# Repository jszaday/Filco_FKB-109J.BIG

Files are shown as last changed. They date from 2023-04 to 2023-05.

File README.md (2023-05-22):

# Universa Universis
Retrofit PCB for various Alps full-sized keyboards.

## Planned support:
- AEK (ANSI, EUR, JPN)
- DELL AT101W (ANSI, EUR, JPN)
- DELL AT101 (ANSI, EUR, JPN)
- Strong Man SMK-8851 (BAE, JPN)

## Version History:

### Alpha Revision

Front:
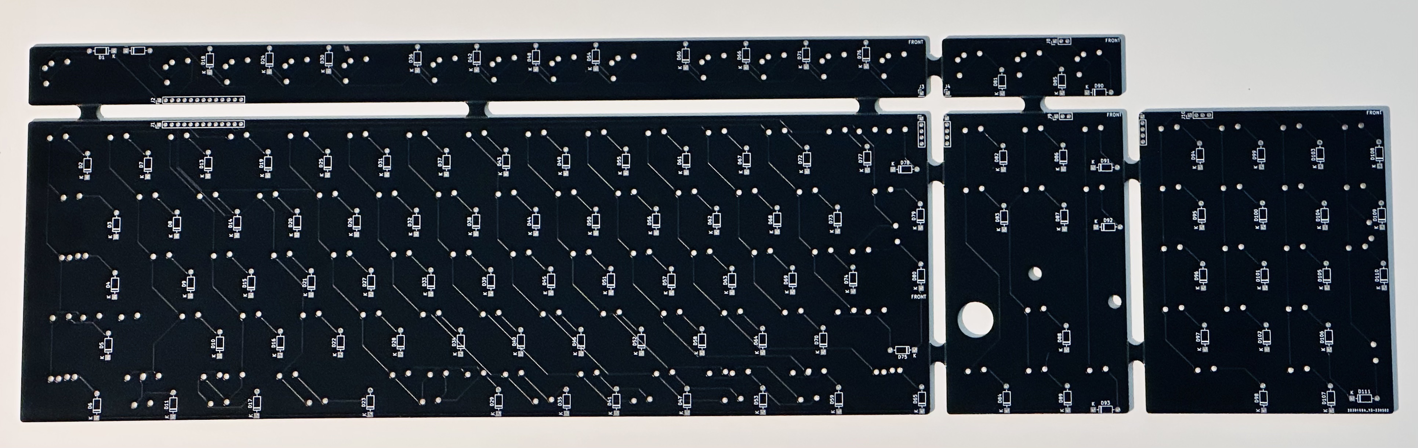
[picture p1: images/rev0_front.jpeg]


Back:
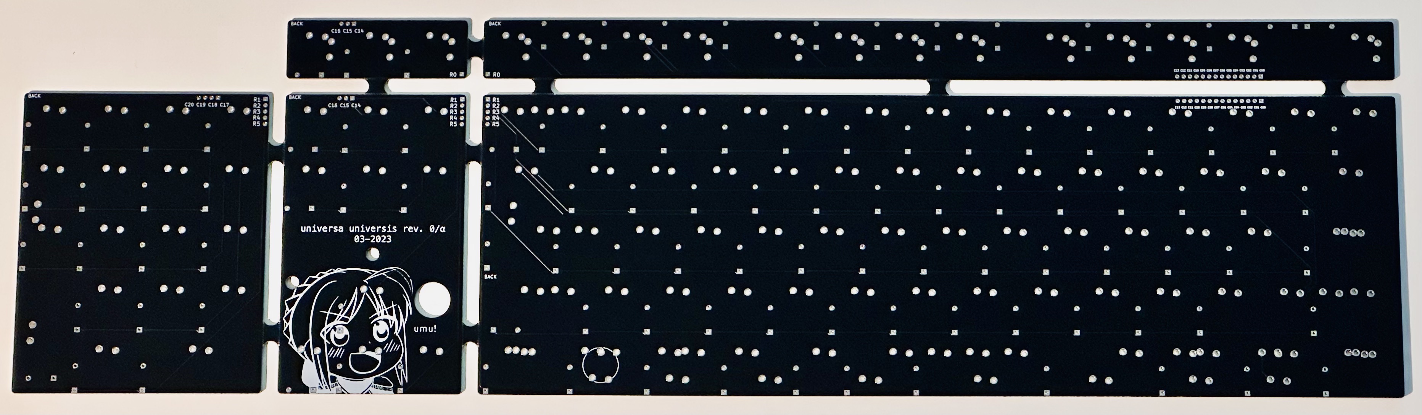
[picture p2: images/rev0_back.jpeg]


#### Known Issues
- DELL AT101 support impeded by unpopable popout between RAlt and RCtrl.
- ISO Enter in wrong position (1.5u vs. 1u); can fold down leads of switch to compensate.
- Num pad plus and enter key switches rotated 180° (not a significant issue).
- No LED carrier board.

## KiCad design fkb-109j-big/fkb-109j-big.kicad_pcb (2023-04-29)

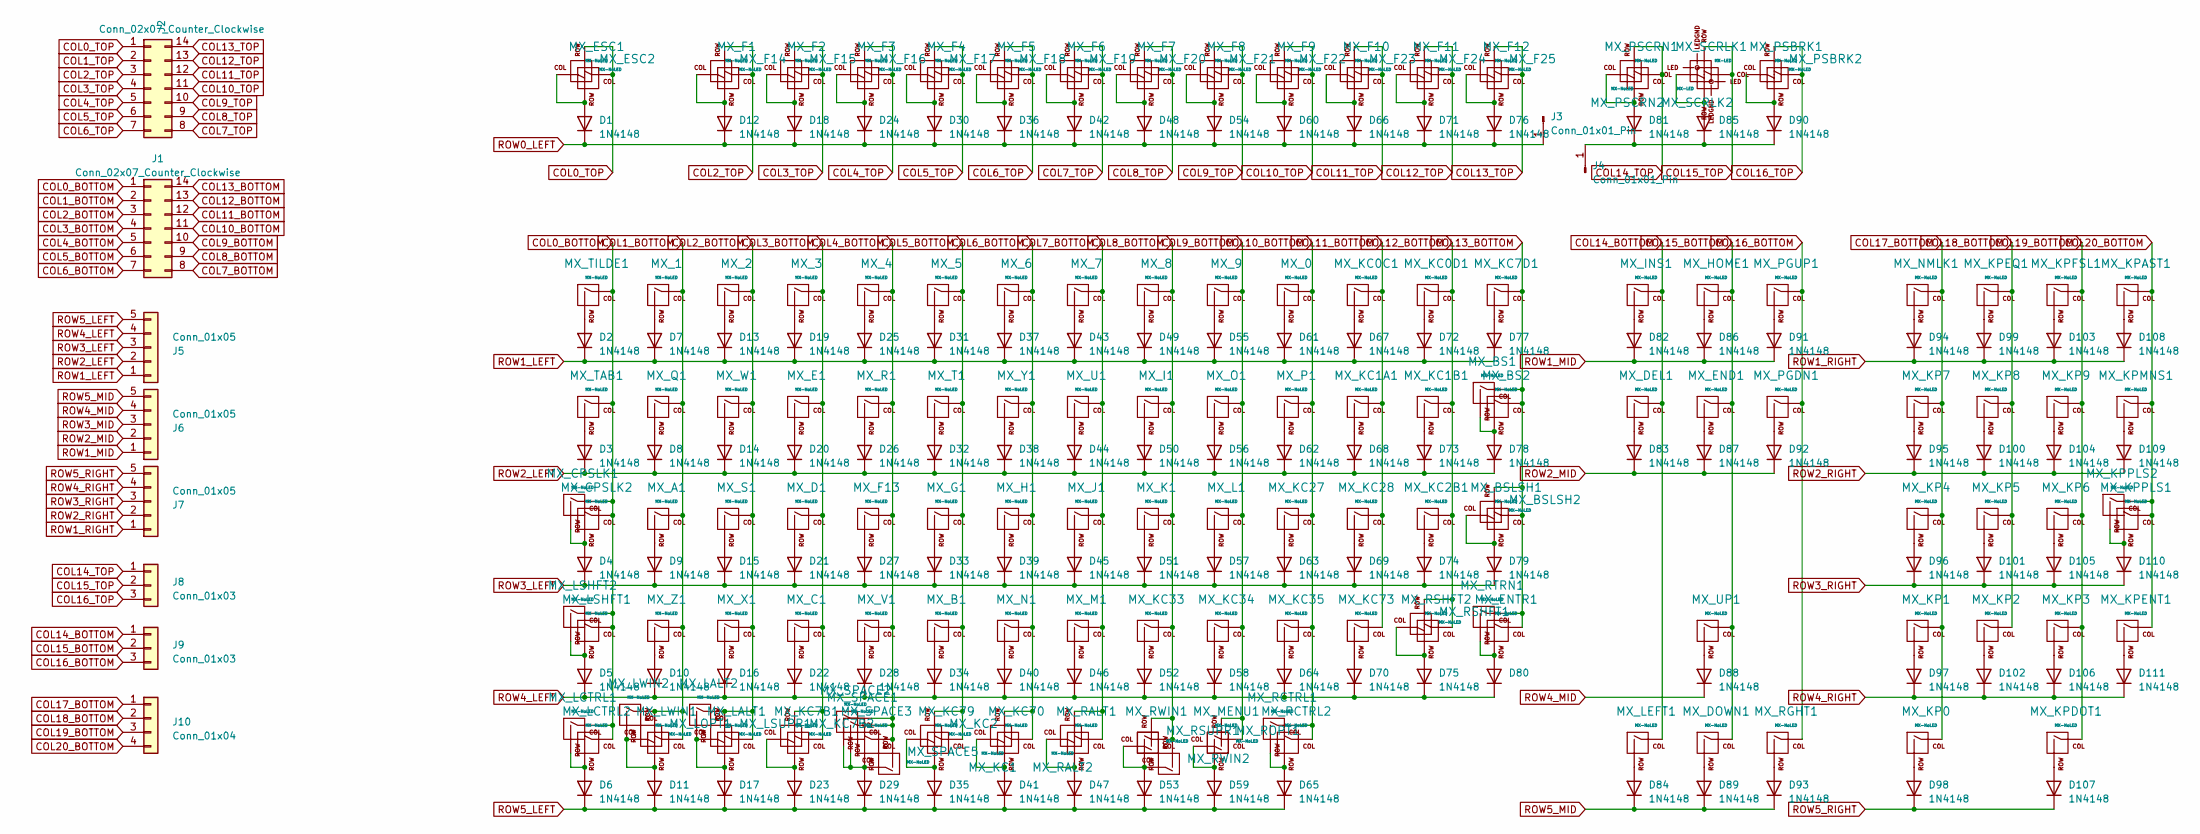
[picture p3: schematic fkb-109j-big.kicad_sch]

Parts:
D1, D2, D3, D4, D5, D6, D7, D8, D9, D10, D11, D12, D13, D14, D15, D16, D17, D18, D19, D20, D21, D22, D23, D24, D25, D26, D27, D28, D29, D30, D31, D32, D33, D34, D35, D36, D37, D38, D39, D40, D41, D42, D43, D44, D45, D46, D47, D48, D49, D50, D51, D52, D53, D54, D55, D56, D57, D58, D59, D60, D61, D62, D63, D64, D65, D66, D67, D68, D69, D70, D71, D72, D73, D74, D75, D76, D77, D78, D79, D80, D81, D82, D83, D84, D85, D86, D87, D88, D89, D90, D91, D92, D93, D94, D95, D96, D97, D98, D99, D100, D101, D102, D103, D104, D105, D106, D107, D108, D109, D110, D111: 1N4148; D_DO-35_SOD27_P7.62mm_Horizontal
J1, J2: Conn_02x07_Counter_Clockwise; PinHeader_1x14_P2.00mm_Vertical
J3, J4: Conn_01x01_Pin; PinHeader_1x01_P2.00mm_Vertical
J5, J6, J7: Conn_01x05; PinHeader_1x05_P2.00mm_Vertical
J8, J9: Conn_01x03; PinHeader_1x03_P2.00mm_Vertical
J10: Conn_01x04; PinHeader_1x04_P2.00mm_Vertical
MX_0, MX_1, MX_2, MX_3, MX_4, MX_5, MX_6, MX_7, MX_8, MX_9: MX-NoLED; ALPS-1U
MX_A1: MX-NoLED; ALPS-1U
MX_B1: MX-NoLED; ALPS-1U
MX_BS1: MX-NoLED; ALPS-1U
MX_BS2: MX-NoLED; ALPS-2U
MX_BSLSH1: MX-NoLED; ALPS-1.5U
MX_BSLSH2: MX-NoLED; ALPS-1U
MX_C1: MX-NoLED; ALPS-1U
MX_CPSLK1: MX-NoLED; ALPS-1.5U
MX_CPSLK2: MX-NoLED; ALPS-1.75U
MX_D1: MX-NoLED; ALPS-1U
MX_DEL1: MX-NoLED; ALPS-1U
MX_DOWN1: MX-NoLED; ALPS-1U
MX_E1: MX-NoLED; ALPS-1U
MX_END1: MX-NoLED; ALPS-1U
MX_ENTR1: MX-NoLED; ALPS-2U
MX_ESC1, MX_ESC2: MX-NoLED; ALPS-1U
MX_F1, MX_F2, MX_F3, MX_F4, MX_F5, MX_F6, MX_F7, MX_F8, MX_F9, MX_F10, MX_F11, MX_F12, MX_F13, MX_F14, MX_F15, MX_F16, MX_F17, MX_F18, MX_F19, MX_F20, MX_F21, MX_F22, MX_F23, MX_F24, MX_F25: MX-NoLED; ALPS-1U
MX_G1: MX-NoLED; ALPS-1U
MX_H1: MX-NoLED; ALPS-1U
MX_HOME1: MX-NoLED; ALPS-1U
MX_I1: MX-NoLED; ALPS-1U
MX_INS1: MX-NoLED; ALPS-1U
MX_J1: MX-NoLED; ALPS-1U
MX_K1: MX-NoLED; ALPS-1U
MX_KC0C1, MX_KC0D1, MX_KC1A1, MX_KC1B1, MX_KC2B1, MX_KC7D1, MX_KC27, MX_KC28, MX_KC33, MX_KC34, MX_KC35, MX_KC73: MX-NoLED; ALPS-1U
MX_KC1: MX-NoLED; ALPS-1.5U
MX_KC2, MX_KC7B2: MX-NoLED; ALPS-1.75U
MX_KC7B1, MX_KC70, MX_KC79: MX-NoLED; ALPS-1.25U
MX_KP0: MX-NoLED; ALPS-2U
MX_KP1, MX_KP2, MX_KP3, MX_KP4, MX_KP5, MX_KP6, MX_KP7, MX_KP8, MX_KP9: MX-NoLED; ALPS-1U
MX_KPAST1: MX-NoLED; ALPS-1U
MX_KPDOT1: MX-NoLED; ALPS-1U
MX_KPENT1: MX-NoLED; ALPS-2U
MX_KPEQ1: MX-NoLED; ALPS-1U
MX_KPFSL1: MX-NoLED; ALPS-1U
MX_KPMNS1: MX-NoLED; ALPS-1U
MX_KPPLS1: MX-NoLED; ALPS-1U
MX_KPPLS2: MX-NoLED; ALPS-2U
MX_L1: MX-NoLED; ALPS-1U
MX_LALT1: MX-NoLED; ALPS-1.25U
MX_LALT2: MX-NoLED; ALPS-1.5U
MX_LCTRL1: MX-NoLED; ALPS-1.25U
MX_LCTRL2: MX-NoLED; ALPS-1.5U
MX_LEFT1: MX-NoLED; ALPS-1U
MX_LOPT1: MX-NoLED; ALPS-1.25U
MX_LSHFT1: MX-NoLED; ALPS-2.25U
MX_LSHFT2: MX-NoLED; ALPS-1.25U
MX_LSUPR1: MX-NoLED; ALPS-1.5U
MX_LWIN1: MX-NoLED; ALPS-1.25U
MX_LWIN2: MX-NoLED; ALPS-1U
MX_M1: MX-NoLED; ALPS-1U
MX_MENU1: MX-NoLED; ALPS-1.25U
MX_N1: MX-NoLED; ALPS-1U
MX_NMLK1: MX-NoLED; ALPS-1U
MX_O1: MX-NoLED; ALPS-1U
MX_P1: MX-NoLED; ALPS-1U
MX_PGDN1: MX-NoLED; ALPS-1U
MX_PGUP1: MX-NoLED; ALPS-1U
MX_PSBRK1, MX_PSBRK2: MX-NoLED; ALPS-1U
MX_PSCRN1, MX_PSCRN2: MX-NoLED; ALPS-1U
MX_Q1: MX-NoLED; ALPS-1U
MX_R1: MX-NoLED; ALPS-1U
MX_RALT1: MX-NoLED; ALPS-1.25U
MX_RALT2: MX-NoLED; ALPS-1.5U
MX_RCTRL1: MX-NoLED; ALPS-1.25U
MX_RCTRL2: MX-NoLED; ALPS-1.5U
MX_RGHT1: MX-NoLED; ALPS-1U
MX_ROPT1: MX-NoLED; ALPS-1.25U
MX_RSHFT1: MX-NoLED; ALPS-2.75U
MX_RSHFT2: MX-NoLED; ALPS-1.75U
MX_RSUPR1: MX-NoLED; ALPS-1.5U
MX_RTRN1: MX-NoLED; ALPS-2.25U
MX_RWIN1: MX-NoLED; ALPS-1.25U
MX_RWIN2: MX-NoLED; ALPS-1U
MX_S1: MX-NoLED; ALPS-1U
MX_SCRLK1, MX_SCRLK2: MX-LED; ALPS-1U
MX_SPACE1: MX-NoLED; ALPS-6.5U
MX_SPACE2: MX-NoLED; ALPS-6.25U
MX_SPACE3: MX-NoLED; ALPS-2.5U
MX_SPACE5: MX-NoLED; ALPS-2U
MX_T1: MX-NoLED; ALPS-1U
MX_TAB1: MX-NoLED; ALPS-1.5U
MX_TILDE1: MX-NoLED; ALPS-1U
MX_U1: MX-NoLED; ALPS-1U
MX_UP1: MX-NoLED; ALPS-1U
MX_V1: MX-NoLED; ALPS-1U
MX_W1: MX-NoLED; ALPS-1U
MX_X1: MX-NoLED; ALPS-1U
MX_Y1: MX-NoLED; ALPS-1U
MX_Z1: MX-NoLED; ALPS-1U

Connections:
COL0_BOTTOM: J1.1, MX_CPSLK1.1 (COL), MX_CPSLK2.1 (COL), MX_LCTRL1.1 (COL), MX_LCTRL2.1 (COL), MX_LSHFT1.1 (COL), MX_LSHFT2.1 (COL), MX_TAB1.1 (COL), MX_TILDE1.1 (COL)
COL0_TOP: J2.1, MX_ESC1.1 (COL), MX_ESC2.2 (ROW)
COL1_BOTTOM: J1.2, MX_1.1 (COL), MX_A1.1 (COL), MX_LOPT1.2 (ROW), MX_LWIN1.1 (COL), MX_LWIN2.1 (COL), MX_Q1.1 (COL), MX_Z1.1 (COL)
COL1_TOP: J2.2
COL2_BOTTOM: J1.3, MX_2.1 (COL), MX_LALT1.1 (COL), MX_LALT2.1 (COL), MX_LSUPR1.2 (ROW), MX_S1.1 (COL), MX_W1.1 (COL), MX_X1.1 (COL)
COL2_TOP: J2.3, MX_F1.1 (COL), MX_F14.2 (ROW)
COL3_BOTTOM: J1.4, MX_3.1 (COL), MX_C1.1 (COL), MX_D1.1 (COL), MX_E1.1 (COL), MX_KC7B1.1 (COL), MX_KC7B2.2 (ROW)
COL3_TOP: J2.4, MX_F2.1 (COL), MX_F15.2 (ROW)
COL4_BOTTOM: J1.5, MX_4.1 (COL), MX_F13.1 (COL), MX_R1.1 (COL), MX_SPACE1.1 (COL), MX_SPACE2.1 (COL), MX_SPACE3.1 (COL), MX_SPACE5.2 (ROW), MX_V1.1 (COL)
COL4_TOP: J2.5, MX_F3.1 (COL), MX_F16.2 (ROW)
COL5_BOTTOM: J1.6, MX_5.1 (COL), MX_B1.1 (COL), MX_G1.1 (COL), MX_KC2.2 (ROW), MX_KC79.1 (COL), MX_T1.1 (COL)
COL5_TOP: J2.6, MX_F4.1 (COL), MX_F17.2 (ROW)
COL6_BOTTOM: J1.7, MX_6.1 (COL), MX_H1.1 (COL), MX_KC1.2 (ROW), MX_KC70.1 (COL), MX_N1.1 (COL), MX_Y1.1 (COL)
COL6_TOP: J2.7, MX_F5.1 (COL), MX_F18.2 (ROW)
COL7_BOTTOM: J1.8, MX_7.1 (COL), MX_J1.1 (COL), MX_M1.1 (COL), MX_RALT1.1 (COL), MX_RALT2.2 (ROW), MX_U1.1 (COL)
COL7_TOP: J2.8, MX_F6.1 (COL), MX_F19.2 (ROW)
COL8_BOTTOM: J1.9, MX_8.1 (COL), MX_I1.1 (COL), MX_K1.1 (COL), MX_KC33.1 (COL), MX_RSUPR1.2 (ROW), MX_RWIN1.1 (COL), MX_RWIN2.2 (ROW)
COL8_TOP: J2.9, MX_F7.1 (COL), MX_F20.2 (ROW)
COL9_BOTTOM: J1.10, MX_9.1 (COL), MX_KC34.1 (COL), MX_L1.1 (COL), MX_MENU1.1 (COL), MX_O1.1 (COL), MX_ROPT1.2 (ROW)
COL9_TOP: J2.10, MX_F8.1 (COL), MX_F21.2 (ROW)
COL10_BOTTOM: J1.11, MX_0.1 (COL), MX_KC27.1 (COL), MX_KC35.1 (COL), MX_P1.1 (COL), MX_RCTRL1.1 (COL), MX_RCTRL2.1 (COL)
COL10_TOP: J2.11, MX_F9.1 (COL), MX_F22.2 (ROW)
COL11_BOTTOM: J1.12, MX_KC0C1.1 (COL), MX_KC1A1.1 (COL), MX_KC28.1 (COL), MX_KC73.1 (COL)
COL11_TOP: J2.12, MX_F10.1 (COL), MX_F23.2 (ROW)
COL12_BOTTOM: J1.13, MX_KC0D1.1 (COL), MX_KC1B1.1 (COL), MX_KC2B1.1 (COL), MX_RSHFT1.2 (ROW), MX_RSHFT2.1 (COL)
COL12_TOP: J2.13, MX_F11.1 (COL), MX_F24.2 (ROW)
COL13_BOTTOM: J1.14, MX_BS1.1 (COL), MX_BS2.1 (COL), MX_BSLSH1.1 (COL), MX_BSLSH2.2 (ROW), MX_ENTR1.1 (COL), MX_KC7D1.1 (COL), MX_RTRN1.1 (COL)
COL13_TOP: J2.14, MX_F12.1 (COL), MX_F25.2 (ROW)
COL14_BOTTOM: J9.1, MX_DEL1.1 (COL), MX_INS1.1 (COL), MX_LEFT1.1 (COL)
COL14_TOP: J8.1, MX_PSCRN1.1 (COL), MX_PSCRN2.2 (ROW)
COL15_BOTTOM: J9.2, MX_DOWN1.1 (COL), MX_END1.1 (COL), MX_HOME1.1 (COL), MX_UP1.1 (COL)
COL15_TOP: J8.2, MX_SCRLK1.1 (COL), MX_SCRLK2.2 (ROW)
COL16_BOTTOM: J9.3, MX_PGDN1.1 (COL), MX_PGUP1.1 (COL), MX_RGHT1.1 (COL)
COL16_TOP: J8.3, MX_PSBRK1.1 (COL), MX_PSBRK2.2 (ROW)
COL17_BOTTOM: J10.1, MX_KP0.1 (COL), MX_KP1.1 (COL), MX_KP4.1 (COL), MX_KP7.1 (COL), MX_NMLK1.1 (COL)
COL18_BOTTOM: J10.2, MX_KP2.1 (COL), MX_KP5.1 (COL), MX_KP8.1 (COL), MX_KPEQ1.1 (COL)
COL19_BOTTOM: J10.3, MX_KP3.1 (COL), MX_KP6.1 (COL), MX_KP9.1 (COL), MX_KPDOT1.1 (COL), MX_KPFSL1.1 (COL)
COL20_BOTTOM: J10.4, MX_KPAST1.1 (COL), MX_KPENT1.1 (COL), MX_KPMNS1.1 (COL), MX_KPPLS1.1 (COL), MX_KPPLS2.1 (COL)
unnamed: D1.2 (A), MX_ESC1.2 (ROW), MX_ESC2.1 (COL)
unnamed: D2.2 (A), MX_TILDE1.2 (ROW)
unnamed: D3.2 (A), MX_TAB1.2 (ROW)
unnamed: D4.2 (A), MX_CPSLK1.2 (ROW), MX_CPSLK2.2 (ROW)
unnamed: D5.2 (A), MX_LSHFT1.2 (ROW), MX_LSHFT2.2 (ROW)
unnamed: D6.2 (A), MX_LCTRL1.2 (ROW), MX_LCTRL2.2 (ROW)
unnamed: D7.2 (A), MX_1.2 (ROW)
unnamed: D8.2 (A), MX_Q1.2 (ROW)
unnamed: D9.2 (A), MX_A1.2 (ROW)
unnamed: D10.2 (A), MX_Z1.2 (ROW)
unnamed: D11.2 (A), MX_LOPT1.1 (COL), MX_LWIN1.2 (ROW), MX_LWIN2.2 (ROW)
unnamed: D12.2 (A), MX_F1.2 (ROW), MX_F14.1 (COL)
unnamed: D13.2 (A), MX_2.2 (ROW)
unnamed: D14.2 (A), MX_W1.2 (ROW)
unnamed: D15.2 (A), MX_S1.2 (ROW)
unnamed: D16.2 (A), MX_X1.2 (ROW)
unnamed: D17.2 (A), MX_LALT1.2 (ROW), MX_LALT2.2 (ROW), MX_LSUPR1.1 (COL)
unnamed: D18.2 (A), MX_F2.2 (ROW), MX_F15.1 (COL)
unnamed: D19.2 (A), MX_3.2 (ROW)
unnamed: D20.2 (A), MX_E1.2 (ROW)
unnamed: D21.2 (A), MX_D1.2 (ROW)
unnamed: D22.2 (A), MX_C1.2 (ROW)
unnamed: D23.2 (A), MX_KC7B1.2 (ROW), MX_KC7B2.1 (COL)
unnamed: D24.2 (A), MX_F3.2 (ROW), MX_F16.1 (COL)
unnamed: D25.2 (A), MX_4.2 (ROW)
unnamed: D26.2 (A), MX_R1.2 (ROW)
unnamed: D27.2 (A), MX_F13.2 (ROW)
unnamed: D28.2 (A), MX_V1.2 (ROW)
unnamed: D29.2 (A), MX_SPACE1.2 (ROW), MX_SPACE2.2 (ROW), MX_SPACE3.2 (ROW), MX_SPACE5.1 (COL)
unnamed: D30.2 (A), MX_F4.2 (ROW), MX_F17.1 (COL)
unnamed: D31.2 (A), MX_5.2 (ROW)
unnamed: D32.2 (A), MX_T1.2 (ROW)
unnamed: D33.2 (A), MX_G1.2 (ROW)
unnamed: D34.2 (A), MX_B1.2 (ROW)
unnamed: D35.2 (A), MX_KC2.1 (COL), MX_KC79.2 (ROW)
unnamed: D36.2 (A), MX_F5.2 (ROW), MX_F18.1 (COL)
unnamed: D37.2 (A), MX_6.2 (ROW)
unnamed: D38.2 (A), MX_Y1.2 (ROW)
unnamed: D39.2 (A), MX_H1.2 (ROW)
unnamed: D40.2 (A), MX_N1.2 (ROW)
unnamed: D41.2 (A), MX_KC1.1 (COL), MX_KC70.2 (ROW)
unnamed: D42.2 (A), MX_F6.2 (ROW), MX_F19.1 (COL)
unnamed: D43.2 (A), MX_7.2 (ROW)
unnamed: D44.2 (A), MX_U1.2 (ROW)
unnamed: D45.2 (A), MX_J1.2 (ROW)
unnamed: D46.2 (A), MX_M1.2 (ROW)
unnamed: D47.2 (A), MX_RALT1.2 (ROW), MX_RALT2.1 (COL)
unnamed: D48.2 (A), MX_F7.2 (ROW), MX_F20.1 (COL)
unnamed: D49.2 (A), MX_8.2 (ROW)
unnamed: D50.2 (A), MX_I1.2 (ROW)
unnamed: D51.2 (A), MX_K1.2 (ROW)
unnamed: D52.2 (A), MX_KC33.2 (ROW)
unnamed: D53.2 (A), MX_RSUPR1.1 (COL), MX_RWIN1.2 (ROW), MX_RWIN2.1 (COL)
unnamed: D54.2 (A), MX_F8.2 (ROW), MX_F21.1 (COL)
unnamed: D55.2 (A), MX_9.2 (ROW)
unnamed: D56.2 (A), MX_O1.2 (ROW)
unnamed: D57.2 (A), MX_L1.2 (ROW)
unnamed: D58.2 (A), MX_KC34.2 (ROW)
unnamed: D59.2 (A), MX_MENU1.2 (ROW), MX_ROPT1.1 (COL)
unnamed: D60.2 (A), MX_F9.2 (ROW), MX_F22.1 (COL)
unnamed: D61.2 (A), MX_0.2 (ROW)
unnamed: D62.2 (A), MX_P1.2 (ROW)
unnamed: D63.2 (A), MX_KC27.2 (ROW)
unnamed: D64.2 (A), MX_KC35.2 (ROW)
unnamed: D65.2 (A), MX_RCTRL1.2 (ROW), MX_RCTRL2.2 (ROW)
unnamed: D66.2 (A), MX_F10.2 (ROW), MX_F23.1 (COL)
unnamed: D67.2 (A), MX_KC0C1.2 (ROW)
unnamed: D68.2 (A), MX_KC1A1.2 (ROW)
unnamed: D69.2 (A), MX_KC28.2 (ROW)
unnamed: D70.2 (A), MX_KC73.2 (ROW)
unnamed: D71.2 (A), MX_F11.2 (ROW), MX_F24.1 (COL)
unnamed: D72.2 (A), MX_KC0D1.2 (ROW)
unnamed: D73.2 (A), MX_KC1B1.2 (ROW)
unnamed: D74.2 (A), MX_KC2B1.2 (ROW)
unnamed: D75.2 (A), MX_RSHFT1.1 (COL), MX_RSHFT2.2 (ROW)
unnamed: D76.2 (A), MX_F12.2 (ROW), MX_F25.1 (COL)
unnamed: D77.2 (A), MX_KC7D1.2 (ROW)
unnamed: D78.2 (A), MX_BS1.2 (ROW), MX_BS2.2 (ROW)
unnamed: D79.2 (A), MX_BSLSH1.2 (ROW), MX_BSLSH2.1 (COL)
unnamed: D80.2 (A), MX_ENTR1.2 (ROW), MX_RTRN1.2 (ROW)
unnamed: D81.2 (A), MX_PSCRN1.2 (ROW), MX_PSCRN2.1 (COL)
unnamed: D81.1 (K), D85.1 (K), D90.1 (K), J4.1
unnamed: D82.2 (A), MX_INS1.2 (ROW)
unnamed: D83.2 (A), MX_DEL1.2 (ROW)
unnamed: D84.2 (A), MX_LEFT1.2 (ROW)
unnamed: D85.2 (A), MX_SCRLK1.2 (ROW), MX_SCRLK2.1 (COL)
unnamed: D86.2 (A), MX_HOME1.2 (ROW)
unnamed: D87.2 (A), MX_END1.2 (ROW)
unnamed: D88.2 (A), MX_UP1.2 (ROW)
unnamed: D89.2 (A), MX_DOWN1.2 (ROW)
unnamed: D90.2 (A), MX_PSBRK1.2 (ROW), MX_PSBRK2.1 (COL)
unnamed: D91.2 (A), MX_PGUP1.2 (ROW)
unnamed: D92.2 (A), MX_PGDN1.2 (ROW)
unnamed: D93.2 (A), MX_RGHT1.2 (ROW)
unnamed: D94.2 (A), MX_NMLK1.2 (ROW)
unnamed: D95.2 (A), MX_KP7.2 (ROW)
unnamed: D96.2 (A), MX_KP4.2 (ROW)
unnamed: D97.2 (A), MX_KP1.2 (ROW)
unnamed: D98.2 (A), MX_KP0.2 (ROW)
unnamed: D99.2 (A), MX_KPEQ1.2 (ROW)
unnamed: D100.2 (A), MX_KP8.2 (ROW)
unnamed: D101.2 (A), MX_KP5.2 (ROW)
unnamed: D102.2 (A), MX_KP2.2 (ROW)
unnamed: D103.2 (A), MX_KPFSL1.2 (ROW)
unnamed: D104.2 (A), MX_KP9.2 (ROW)
unnamed: D105.2 (A), MX_KP6.2 (ROW)
unnamed: D106.2 (A), MX_KP3.2 (ROW)
unnamed: D107.2 (A), MX_KPDOT1.2 (ROW)
unnamed: D108.2 (A), MX_KPAST1.2 (ROW)
unnamed: D109.2 (A), MX_KPMNS1.2 (ROW)
unnamed: D110.2 (A), MX_KPPLS1.2 (ROW), MX_KPPLS2.2 (ROW)
unnamed: D111.2 (A), MX_KPENT1.2 (ROW)
ROW0_LEFT: D1.1 (K), D12.1 (K), D18.1 (K), D24.1 (K), D30.1 (K), D36.1 (K), D42.1 (K), D48.1 (K), D54.1 (K), D60.1 (K), D66.1 (K), D71.1 (K), D76.1 (K), J3.1
ROW1_LEFT: D2.1 (K), D7.1 (K), D13.1 (K), D19.1 (K), D25.1 (K), D31.1 (K), D37.1 (K), D43.1 (K), D49.1 (K), D55.1 (K), D61.1 (K), D67.1 (K), D72.1 (K), D77.1 (K), J5.1
ROW1_MID: D82.1 (K), D86.1 (K), D91.1 (K), J6.1
ROW1_RIGHT: D94.1 (K), D99.1 (K), D103.1 (K), D108.1 (K), J7.1
ROW2_LEFT: D3.1 (K), D8.1 (K), D14.1 (K), D20.1 (K), D26.1 (K), D32.1 (K), D38.1 (K), D44.1 (K), D50.1 (K), D56.1 (K), D62.1 (K), D68.1 (K), D73.1 (K), D78.1 (K), J5.2
ROW2_MID: D83.1 (K), D87.1 (K), D92.1 (K), J6.2
ROW2_RIGHT: D95.1 (K), D100.1 (K), D104.1 (K), D109.1 (K), J7.2
ROW3_LEFT: D4.1 (K), D9.1 (K), D15.1 (K), D21.1 (K), D27.1 (K), D33.1 (K), D39.1 (K), D45.1 (K), D51.1 (K), D57.1 (K), D63.1 (K), D69.1 (K), D74.1 (K), D79.1 (K), J5.3
ROW3_MID: J6.3
ROW3_RIGHT: D96.1 (K), D101.1 (K), D105.1 (K), D110.1 (K), J7.3
ROW4_LEFT: D5.1 (K), D10.1 (K), D16.1 (K), D22.1 (K), D28.1 (K), D34.1 (K), D40.1 (K), D46.1 (K), D52.1 (K), D58.1 (K), D64.1 (K), D70.1 (K), D75.1 (K), D80.1 (K), J5.4
ROW4_MID: D88.1 (K), J6.4
ROW4_RIGHT: D97.1 (K), D102.1 (K), D106.1 (K), D111.1 (K), J7.4
ROW5_LEFT: D6.1 (K), D11.1 (K), D17.1 (K), D23.1 (K), D29.1 (K), D35.1 (K), D41.1 (K), D47.1 (K), D53.1 (K), D59.1 (K), D65.1 (K), J5.5
ROW5_MID: D84.1 (K), D89.1 (K), D93.1 (K), J6.5
ROW5_RIGHT: D98.1 (K), D107.1 (K), J7.5

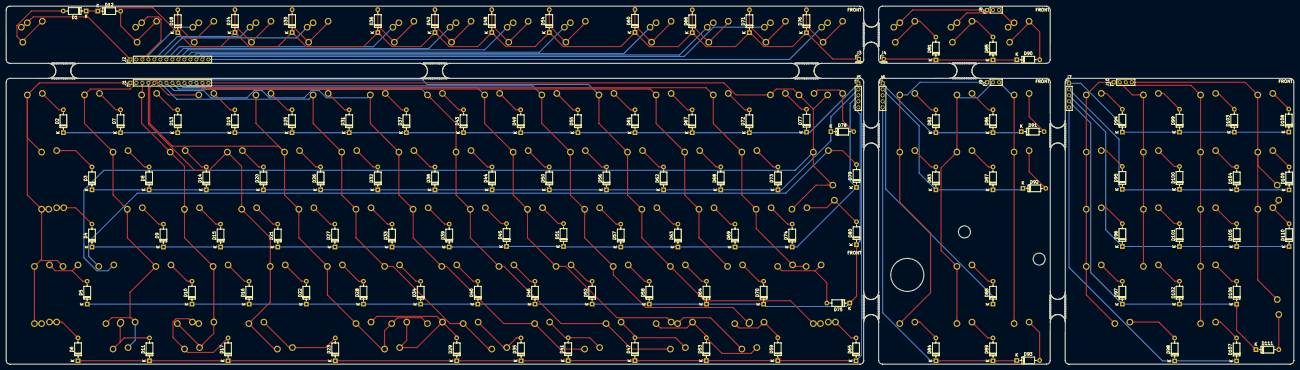
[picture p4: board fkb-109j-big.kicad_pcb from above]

Board: 2 copper layers, 429.1 x 119.3 mm, 280 parts (0 on the bottom side), 164 nets.

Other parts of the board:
mouse-bite-5mm-slot, mouse-bite-5mm-slot#2, mouse-bite-5mm-slot#3, mouse-bite-5mm-slot#4, mouse-bite-5mm-slot#5, mouse-bite-5mm-slot#6, mouse-bite-5mm-slot#7, mouse-bite-5mm-slot#8, mouse-bite-5mm-slot#9: VAL**; mouse-bite-5mm-slot

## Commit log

2023-04-23 initialize project
    [fkb-109j-big.kicad_pcb, fkb-109j-big.kicad_sch]
2023-04-24 Start establishing layout
    [fkb-109j-big.kicad_sch]
2023-04-24 start board layout
    [fkb-109j-big.kicad_pcb, fkb-109j-big.kicad_sch]
2023-04-25 continue layout
    [fkb-109j-big.kicad_pcb, fkb-109j-big.kicad_sch]
2023-04-25 fix footprint
    [fkb-109j-big.kicad_sch]
2023-04-25 finish preliminary layout
    [fkb-109j-big.kicad_pcb, fkb-109j-big.kicad_sch]
2023-04-25 start moving diodes
    [fkb-109j-big.kicad_pcb, fkb-109j-big.kicad_sch]
2023-04-25 add 7u/jis bottom-row
    [fkb-109j-big.kicad_pcb, fkb-109j-big.kicad_sch]
2023-04-25 continue placing diodes
    [fkb-109j-big.kicad_pcb, fkb-109j-big.kicad_sch]
2023-04-25 finish preliminary diode placement.
    [fkb-109j-big.kicad_pcb]
2023-04-26 panelize all the things
    [fkb-109j-big.kicad_pcb]
2023-04-26 layout cont.
    [fkb-109j-big.kicad_pcb, fkb-109j-big.kicad_sch]
2023-04-27 layout... done?
    [fkb-109j-big.kicad_pcb, fkb-109j-big.kicad_sch]
2023-04-28 add some holes.
    [fkb-109j-big.kicad_pcb]
2023-04-28 add umu; minor cleanup.
    [fkb-109j-big.kicad_pcb]
2023-04-28 start rounding corners
    [fkb-109j-big.kicad_pcb]
2023-04-29 finish rounding out corners.
    [fkb-109j-big.kicad_pcb]
2023-04-29 add teardrops.
    [fkb-109j-big.kicad_pcb]
